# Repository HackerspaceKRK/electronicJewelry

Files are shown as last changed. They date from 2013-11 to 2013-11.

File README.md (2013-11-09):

electronicJewelry
=================

Electronic jewelry made for workshops on TEDx Kraków 2013

Dependencies:
arm-none-eabi toolchain

CodeSourcery toolchain:
http://www.mentor.com/embedded-software/sourcery-tools/sourcery-codebench/editions/lite-edition/
download EABI Release.

Compile with:
./do compile

and your .bin and .hex file is inside build/ directory

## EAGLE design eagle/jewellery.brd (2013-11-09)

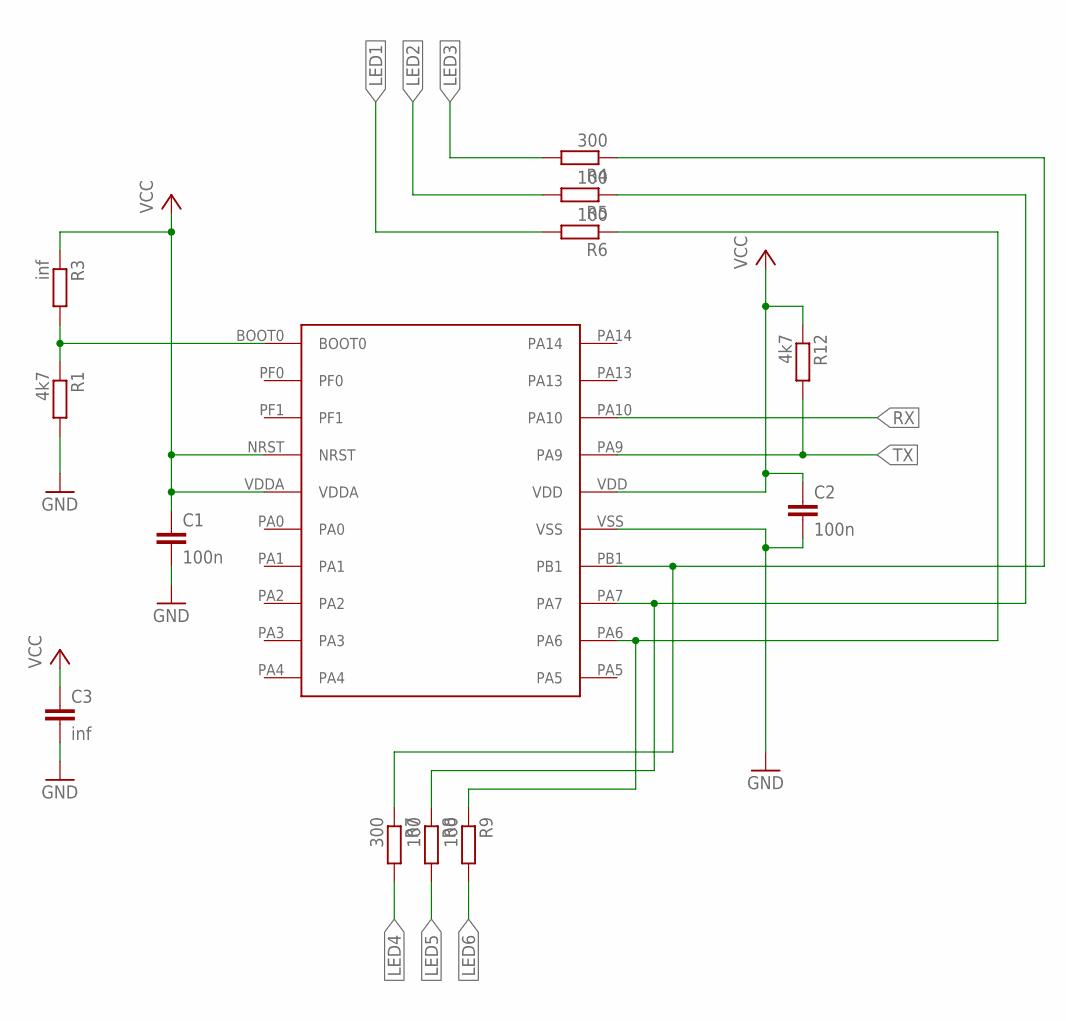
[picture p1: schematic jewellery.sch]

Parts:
C1, C2: 100n; C0805
C3: inf; C0805
R1, R12: 4k7; R0805
R3: inf; R0805
R4, R7: 300; R0805
R5, R6, R8, R9: 100; R0805
U$1: STM32F0; TSSOP20

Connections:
GND: C1.2, C2.2, C3.2, R1.2, U$1.VSS
LED1: R6.2
LED2: R5.2
LED3: R4.2
LED4: R7.2
LED5: R8.2
LED6: R9.2
unnamed: R1.1, R3.2, U$1.BOOT0
unnamed: R4.1, R7.1, U$1.PB1
unnamed: R5.1, R8.1, U$1.PA7
unnamed: R6.1, R9.1, U$1.PA6
RX: U$1.PA10
TX: R12.2, U$1.PA9
VCC: C1.1, C2.1, C3.1, R3.1, R12.1, U$1.NRST, U$1.VDD, U$1.VDDA

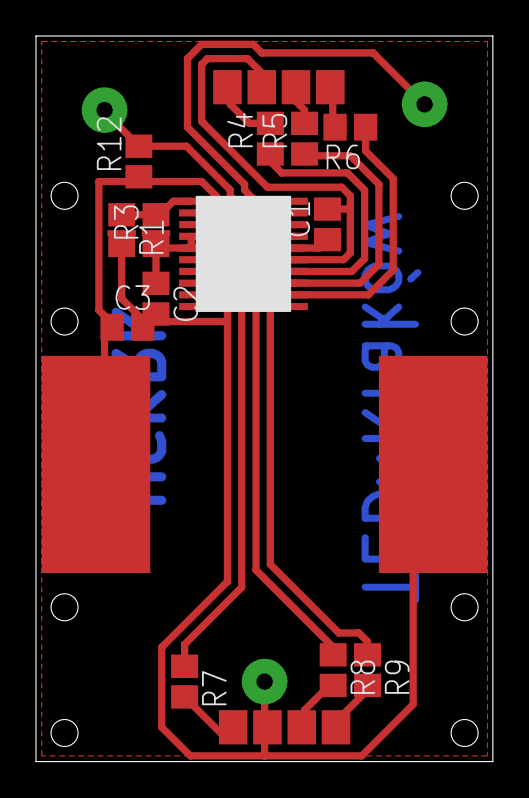
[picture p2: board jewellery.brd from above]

Board: 2 copper layers, 25.4 x 40.3 mm, 13 parts (0 on the bottom side), 7 nets.

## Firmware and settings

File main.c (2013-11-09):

#include <public.h>
#include <delay.h>

#include "comm.h"
#include "hardware.h"

extern uint8_t hsvData[][3];

volatile uint32_t ticks = 0;
int speed = 10;

unsigned int holdrand;
void srand (unsigned int seed)
{
	holdrand = (long)seed;
}
int rand ()
{
	return (((holdrand = holdrand * 214013L + 2531011L) >> 16) & 0x7fff);
}
int randminmax (int min, int max)
{
	return rand () % (max - min) + min;
}

void myputchar (int c)
{
	USART1->TDR = c;
	while (!(USART1->ISR & USART_ISR_TC));
}

int main ()
{
	SYSCFG->CFGR1 = 0;

	RCC->APB1ENR |= RCC_APB1ENR_TIM3EN;
	RCC->APB2ENR |= RCC_APB2ENR_TIM1EN | RCC_APB2ENR_SYSCFGEN | RCC_APB2ENR_USART1EN | RCC_APB2ENR_ADC1EN;
	RCC->AHBENR |= RCC_AHBENR_GPIOCEN | RCC_AHBENR_GPIOAEN | RCC_AHBENR_GPIOBEN;
	
	SysTick->LOAD = SysTick->VAL = (F_CPU / 1000) / 8;
	SysTick->CTRL = SysTick_CTRL_ENABLE_Msk | SysTick_CTRL_TICKINT_Msk;

	_delay_init ();

	ADC1->CR = ADC_CR_ADEN;
	while (!(ADC1->ISR & ADC_ISR_ADRDY));
	ADC->CCR = ADC_CCR_VREFEN;

	uint32_t adcSeed;
	int i, j;
	for (j = 0; j < 100; j++)
	{
		uint32_t tmp = 0;
		for (i = 0; i < 32; i++)
		{
			ADC1->CR = ADC_CR_ADSTART;
			while (!(ADC1->ISR & ADC_ISR_EOC));
			uint32_t d = ADC1->DR;
			tmp <<= 1;
			if (d & 1) tmp |= 1;
		}
		adcSeed ^= tmp;
	}
	if (adcSeed == 0) adcSeed = 1;
	if (adcSeed == 0xffffffff) adcSeed = 1;
	srand (adcSeed);

	uint16_t *mem = (uint16_t*)(0x08000000 + (16 - 1) * 1024);

	if (*mem == 0xffff)
	{
		FLASH->CR |= FLASH_CR_LOCK;
		FLASH->KEYR = 0x45670123;
		FLASH->KEYR = 0xCDEF89AB;
		while (FLASH->CR & FLASH_CR_LOCK);

		FLASH->CR = FLASH_CR_PG;

		mykey = randminmax (0, 360);
		*mem = mykey;
		while (FLASH->SR & FLASH_SR_BSY);
		FLASH->CR |= FLASH_CR_LOCK;
	}
	else
	{
		mykey = *mem;
	}

	ADC1->CR = ADC_CR_ADDIS;

	ticks = rand ();
	speed = randminmax (3, 13);

	IO_ALT_PUSH_PULL(LEDR);
	IO_ALT_PUSH_PULL(LEDG);
	IO_ALT_PUSH_PULL(LEDB);
	IO_ALT_SET(LEDR, 1);
	IO_ALT_SET(LEDG, 1);
	IO_ALT_SET(LEDB, 1);

	TIM3->CNT = 0;
	TIM3->PSC = 512;
	TIM3->ARR = 256;
	TIM3->BDTR = TIM_BDTR_MOE;
	TIM3->CCMR1 = TIM_CCMR1_OC1M_2 | TIM_CCMR1_OC1M_1 | TIM_CCMR1_OC2M_2 | TIM_CCMR1_OC2M_1;
	TIM3->CCMR2 = TIM_CCMR2_OC3M_2 | TIM_CCMR2_OC3M_1 | TIM_CCMR2_OC4M_2 | TIM_CCMR2_OC4M_1;
	TIM3->CCER = TIM_CCER_CC1E | TIM_CCER_CC2E | TIM_CCER_CC3E | TIM_CCER_CC4E;
	TIM3->CR1 = TIM_CR1_CEN | TIM_CR1_ARPE;

	// for(;;)
	// {
	// TIM3->CCR1 = TIM3->CCR2 = TIM3->CCR4 = 0;
	// TIM3->CCR1 = 255;
	// _delay_ms(4000);
	// TIM3->CCR1 = TIM3->CCR2 = TIM3->CCR4 = 0;
	// TIM3->CCR2 = 255;
	// _delay_ms(4000);
	// TIM3->CCR1 = TIM3->CCR2 = TIM3->CCR4 = 0;
	// TIM3->CCR4 = 255;
	// _delay_ms(4000);
	// }

	commInit ();

	for (;;)
	{
		if (!commIsLocked)
			showColor (ticks / speed);

		commProcess ();
	}
}
void showColor (uint16_t u)
{
	uint8_t *val = hsvData[u % 360];
	TIM3->CCR1 = val[0];
	TIM3->CCR2 = val[1];
	TIM3->CCR4 = val[2];
}
void _errorloop ()
{
	IO_PUSH_PULL(LEDR);
	IO_PUSH_PULL(LEDG);
	IO_PUSH_PULL(LEDB);
	IO_LOW(LEDG);
	IO_LOW(LEDB);
	while (1)
	{
		IO_TOGGLE(LEDR);
		_delay_ms (100);
	}
}
void SysTick_Handler ()
{
	ticks++;
}

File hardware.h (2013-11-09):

#ifndef __HARDWARE_H__
#define __HARDWARE_H__

#define UART_TX GPIOA,9
#define UART_RX GPIOA,10

#define LEDR GPIOB,1 // TIM3_4 - AF1
#define LEDG GPIOA,7 // TIM3_2 - AF1
#define LEDB GPIOA,6 // TIM3_1 - AF1

// pady: red(1.8V), green(2.45), blue(2.58)
//       4mA
//       300R     , 100R       , 100R

#endif

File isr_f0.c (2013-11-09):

extern void main ();
void _errorloop () __attribute__ ((noreturn));

void Reset_Handler ();
extern void NMI_Handle ();
extern void HardFault_Handler ();
extern void SVCall_Handler ();
extern void PendSV_Handler ();
extern void SysTick_Handler ();

extern void WWDG_Handler ();
extern void RTC_Handler ();
extern void FLASH_Handler ();
extern void RCC_Handler ();
extern void EXTI0_1_Handler ();
extern void EXTI2_3_Handler ();
extern void EXTI4_15_Handler ();
extern void DMA1_Channel1_Handler ();
extern void DMA1_Channel2_3_Handler ();
extern void DMA1_Channel4_5_Handler ();
extern void ADC_Handler ();
extern void TIM1_BRK_UP_TRG_COM_Handler ();
extern void TIM1_CC_Handler ();
extern void TIM3_Handler ();
extern void TIM14_Handler ();
extern void TIM15_Handler ();
extern void TIM16_Handler ();
extern void TIM17_Handler ();
extern void I2C1_Handler ();
extern void I2C2_Handler ();
extern void SPI1_Handler ();
extern void SPI2_Handler ();
extern void USART1_Handler ();
extern void USART2_Handler ();

typedef void (*pfnISR)(void);

__attribute__ ((section(".isr_vector")))
pfnISR VectorTable[] =  
{ 
  (pfnISR)(0x20000000 + RAMSIZE), // The initial stack pointer is the top of SRAM 
  Reset_Handler,
  NMI_Handle, 
  HardFault_Handler,
  0,
  0,
  0,
  0,
  0,
  0,
  0,
  SVCall_Handler,
  0,
  0,
  PendSV_Handler,
  SysTick_Handler,

	/*  0 */ 0, // WWDG_Handler,
	/*  1 */ 0, // Reserved,
	/*  2 */ 0, // RTC_Handler,
	/*  3 */ 0, // FLASH_Handler,
	/*  4 */ 0, // RCC_Handler,
	/*  5 */ 0, // EXTI0_1_Handler,
	/*  6 */ 0, // EXTI2_3_Handler,
	/*  7 */ 0, // EXTI4_15_Handler,
	/*  8 */ 0, // Reserved,
	/*  9 */ 0, // DMA1_Channel1_Handler,
	/* 10 */ 0, // DMA1_Channel2_3_Handler,
	/* 11 */ 0, // DMA1_Channel4_5_Handler,
	/* 12 */ 0, // ADC_Handler,
	/* 13 */ 0, // TIM1_BRK_UP_TRG_COM_Handler,
	/* 14 */ 0, // TIM1_CC_Handler,
	/* 15 */ 0, // Reserved,
	/* 16 */ 0, // TIM3_Handler,
	/* 17 */ 0, // Reserved,
	/* 18 */ 0, // Reserved,
	/* 19 */ 0, // TIM14_Handler,
	/* 20 */ 0, // TIM15_Handler,
	/* 21 */ 0, // TIM16_Handler,
	/* 22 */ 0, // TIM17_Handler,
	/* 23 */ 0, // I2C1_Handler,
	/* 24 */ 0, // I2C2_Handler,
	/* 25 */ 0, // SPI1_Handler,
	/* 26 */ 0, // SPI2_Handler,
	/* 27 */ USART1_Handler,
	/* 28 */ 0, // USART2_Handler,
	/* 29 */ 0, // Reserved,
	/* 30 */ 0, // Reserved,
	/* 31 */ 0, // Reserved,
};

extern unsigned long _eisr_vector;
extern unsigned long _text;
extern unsigned long _etext; 
extern unsigned long _data; 
extern unsigned long _edata; 
extern unsigned long _bss; 
extern unsigned long _ebss; 
extern unsigned long _sidata; 
extern unsigned long _sdata; 

void Reset_Handler () 
{ 
  unsigned long *src, *dst; 

  src = &_sidata;
  dst = &_sdata;
  while (dst < &_edata)
    *dst++ = *src++;

	dst = &_bss;
	while (dst < &_ebss)
    *dst++ = 0; 

  main ();
} 
void NMI_Handle () { _errorloop (); }
void HardFault_Handler () { _errorloop (); }
void SVCall_Handler () { _errorloop (); }
void PendSV_Handler () { _errorloop (); }
